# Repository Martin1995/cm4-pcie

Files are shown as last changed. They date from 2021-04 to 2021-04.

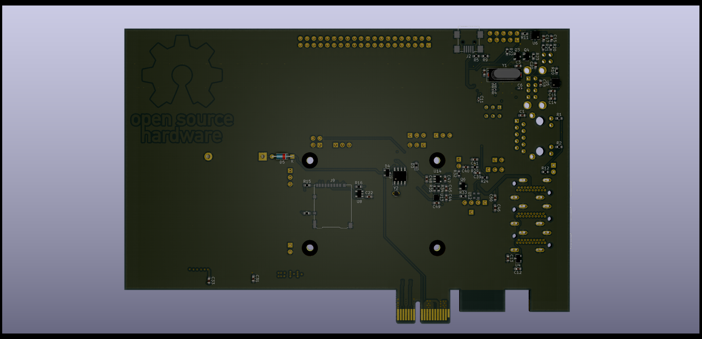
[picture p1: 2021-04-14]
CM4-pcie-rear.png

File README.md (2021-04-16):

# cm4-pcie
TODO:
-Connect HPD of HDMI In to the right pin on the Toshiba HDMI CSI-2 bridge

Feel free to copy the design, I'm not a Highspeed PCB expert, but if you want to use this PCB Design, to create a PCIe Card sized Raspberry Pi CM4 Carrier Board that can plug in to a PCIe Backplane feel free to do so.

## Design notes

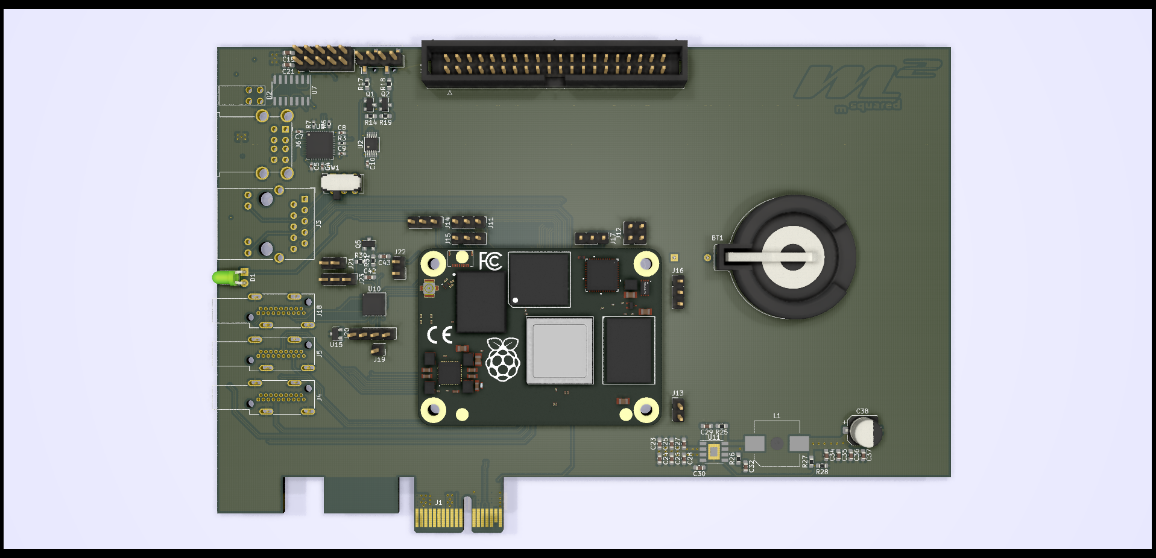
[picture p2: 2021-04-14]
CM4-pcie-front.png

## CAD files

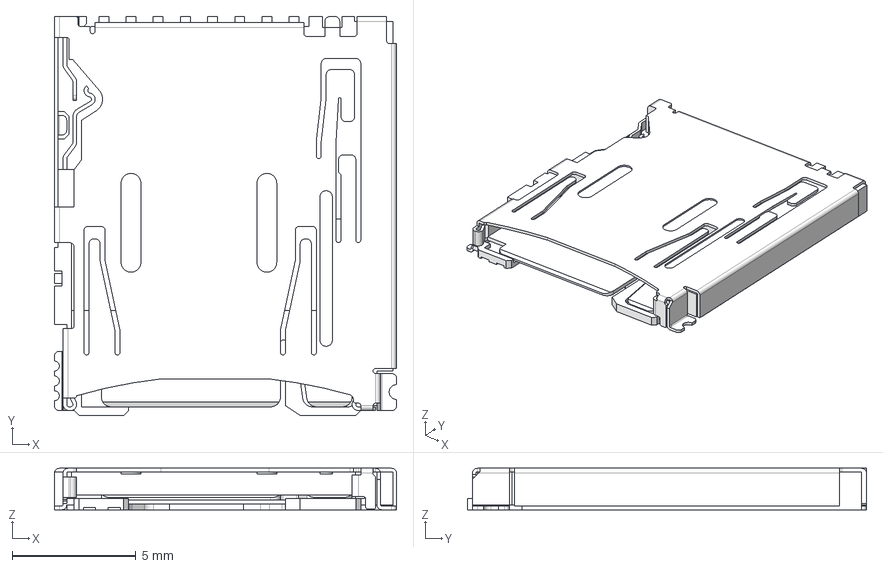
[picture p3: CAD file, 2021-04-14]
DM3AT-SF-PEJM5.stp
13.8 x 16.2 x 1.68 mm

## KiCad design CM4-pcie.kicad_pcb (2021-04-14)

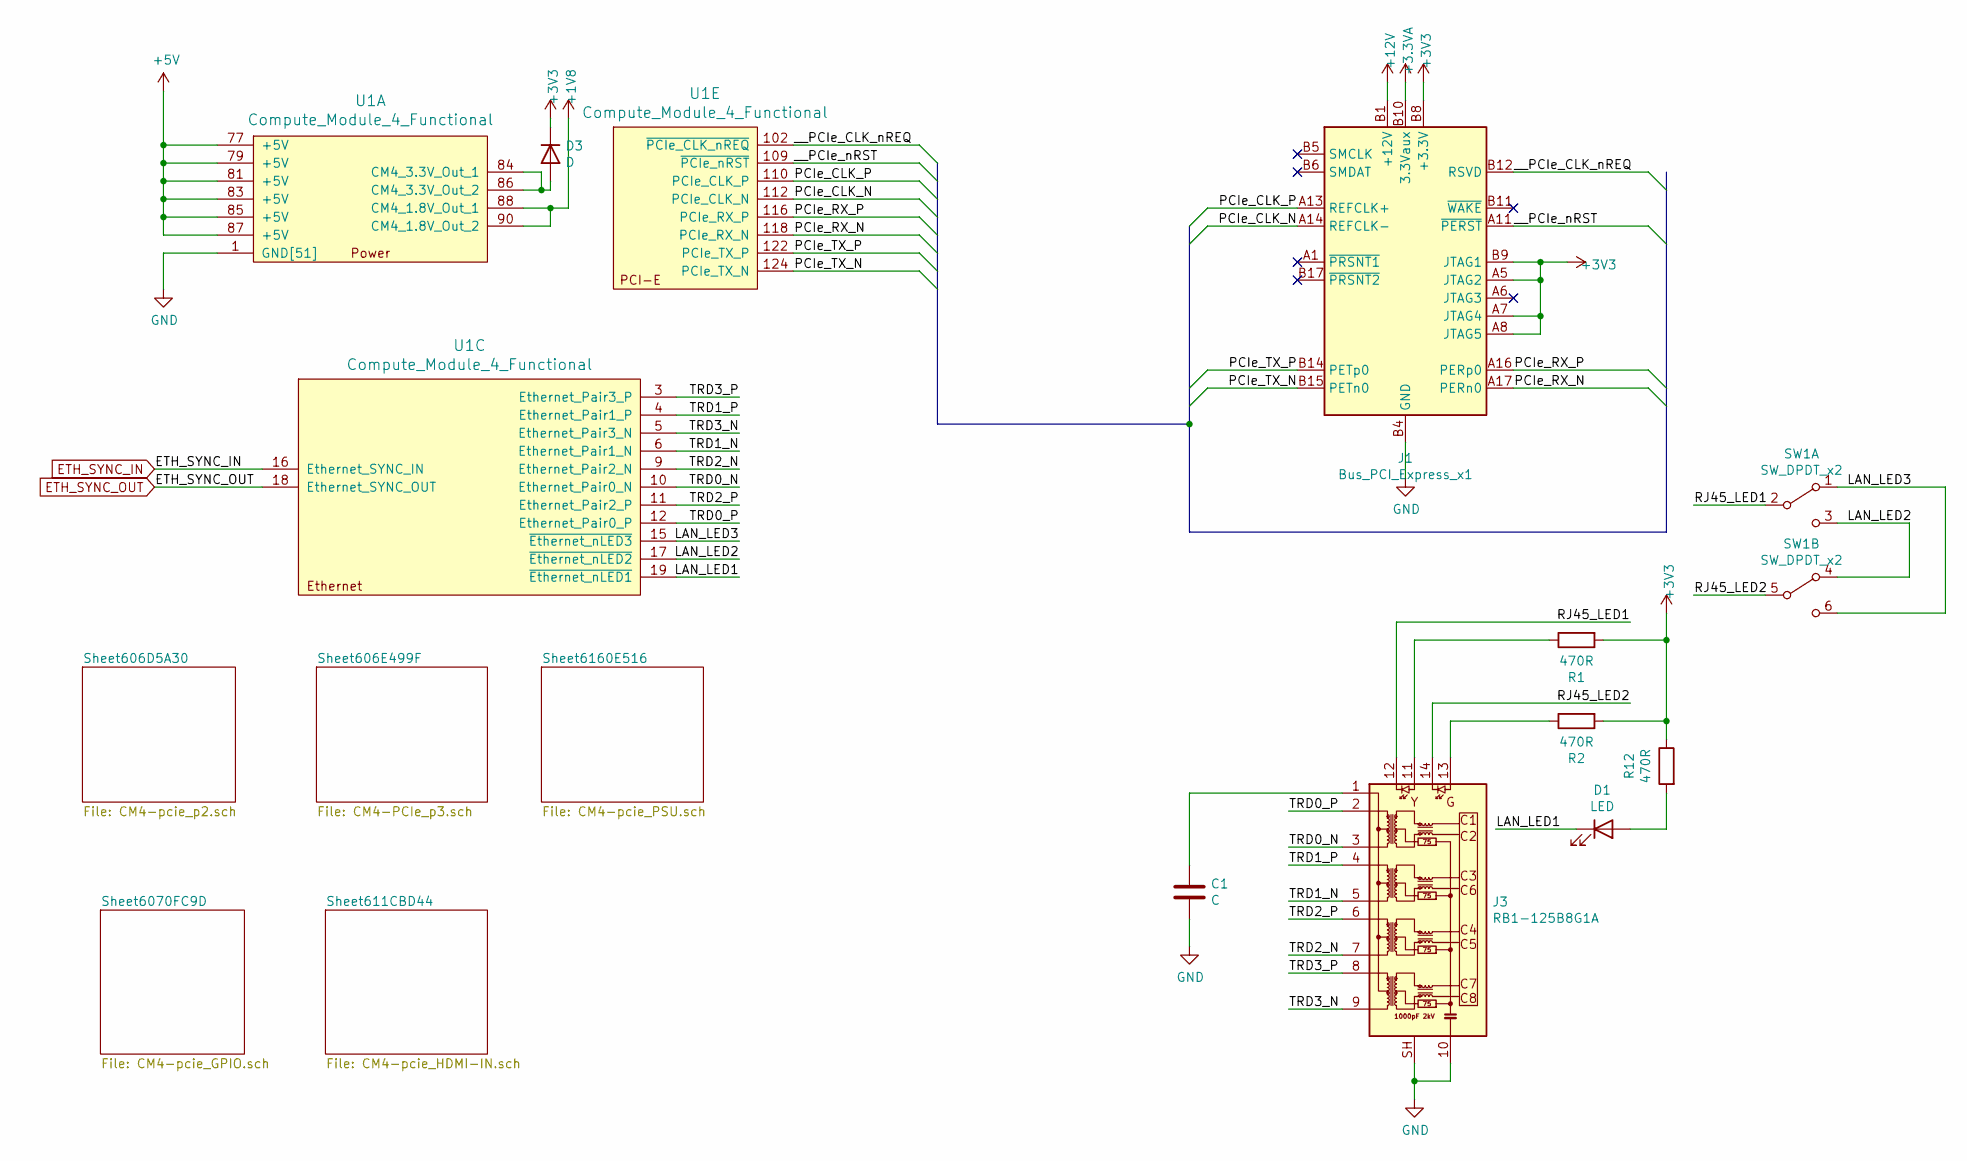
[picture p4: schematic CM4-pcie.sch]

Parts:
C1: C; C_0603_1608Metric_Pad1.08x0.95mm_HandSolder
D1: LED; LED_D3.0mm_Horizontal_O1.27mm_Z2.0mm
D3: D; D_0603_1608Metric_Pad1.05x0.95mm_HandSolder
J1: Bus_PCI_Express_x1; BUS_PCIexpress_x1
J3: RB1-125B8G1A; RJ45_Wuerth_7499111446_Horizontal
R1, R2, R12: 470R; R_0603_1608Metric_Pad0.98x0.95mm_HandSolder
SW1: SW_DPDT_x2; SW_CuK_JS202011AQN_DPDT_Angled
U1: Compute_Module_4_Functional; Raspberry-Pi-4-Compute-Module

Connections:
+1V8: U1.88 (CM4_1.8V_Out_1), U1.90 (CM4_1.8V_Out_2); also elsewhere on the board
+3.3VA: J1.B10 (3.3Vaux); also elsewhere on the board
+3V3: D3.1 (K), J1.A5 (JTAG2), J1.A7 (JTAG4), J1.A8 (JTAG5), J1.A9 (+3.3V), J1.A10 (+3.3V), J1.B8 (+3.3V), J1.B9 (JTAG1), R1.2, R2.2, R12.1; also elsewhere on the board
+5V: U1.77 (+5V), U1.79 (+5V), U1.81 (+5V), U1.83 (+5V), U1.85 (+5V), U1.87 (+5V); also elsewhere on the board
+12V: J1.A2 (+12V), J1.A3 (+12V), J1.B1 (+12V), J1.B2 (+12V), J1.B3 (+12V); also elsewhere on the board
/LAN_LED1: D1.1 (K), U1.19 (~Ethernet_nLED1)
/LAN_LED2: SW1.3 (C), SW1.4 (A), U1.17 (~Ethernet_nLED2)
/LAN_LED3: SW1.1 (A), SW1.6 (C), U1.15 (~Ethernet_nLED3)
/PCIe_CLK_N: J1.A14 (REFCLK-), U1.112 (PCIe_CLK_N)
/PCIe_CLK_P: J1.A13 (REFCLK+), U1.110 (PCIe_CLK_P)
/PCIe_RX_N: J1.A17 (PERn0), U1.118 (PCIe_RX_N)
/PCIe_RX_P: J1.A16 (PERp0), U1.116 (PCIe_RX_P)
/PCIe_TX_N: J1.B15 (PETn0), U1.124 (PCIe_TX_N)
/PCIe_TX_P: J1.B14 (PETp0), U1.122 (PCIe_TX_P)
/RJ45_LED1: J3.12, SW1.2 (B)
/RJ45_LED2: J3.14, SW1.5 (B)
/TRD0_N: J3.3 (TD1-), U1.10 (Ethernet_Pair0_N)
/TRD0_P: J3.2 (TD1+), U1.12 (Ethernet_Pair0_P)
/TRD1_N: J3.5 (TD2-), U1.6 (Ethernet_Pair1_N)
/TRD1_P: J3.4 (TD2+), U1.4 (Ethernet_Pair1_P)
/TRD2_N: J3.7 (TD3-), U1.9 (Ethernet_Pair2_N)
/TRD2_P: J3.6 (TD3+), U1.11 (Ethernet_Pair2_P)
/TRD3_N: J3.9 (TD4-), U1.5 (Ethernet_Pair3_N)
/TRD3_P: J3.8 (TD4+), U1.3 (Ethernet_Pair3_P)
/__PCIe_CLK_nREQ: J1.B12 (RSVD), U1.102 (~PCIe_CLK_nREQ)
/__PCIe_nRST: J1.A11 (~PERST), U1.109 (~PCIe_nRST)
ETH_SYNC_IN: U1.16 (Ethernet_SYNC_IN); also elsewhere on the board
ETH_SYNC_OUT: U1.18 (Ethernet_SYNC_OUT); also elsewhere on the board
GND: C1.2, J1.A4 (GND), J1.A12 (GND), J1.A15 (GND), J1.A18 (GND), J1.B4 (GND), J1.B7 (GND), J1.B13 (GND), J1.B16 (GND), J1.B18 (GND), J3.10 (GND), J3.SH, U1.1 (GND[51]), U1.2 (GND[51]), U1.7 (GND[51]), U1.8 (GND[51]), U1.13 (GND[51]), U1.14 (GND[51]), U1.22 (GND[51]), U1.23 (GND[51]), U1.32 (GND[51]), U1.33 (GND[51]), U1.42 (GND[51]), U1.43 (GND[51]), U1.52 (GND[51]), U1.53 (GND[51]), U1.59 (GND[51]), U1.60 (GND[51]), U1.65 (GND[51]), U1.66 (GND[51]), U1.71 (GND[51]), U1.74 (GND[51]), U1.98 (GND[51]), U1.107 (GND[51]), U1.108 (GND[51]), U1.113 (GND[51]), U1.114 (GND[51]), U1.119 (GND[51]), U1.120 (GND[51]), U1.125 (GND[51]), U1.126 (GND[51]), U1.131 (GND[51]), U1.132 (GND[51]), U1.137 (GND[51]), U1.138 (GND[51]), U1.144 (GND[51]), U1.150 (GND[51]), U1.155 (GND[51]), U1.156 (GND[51]), U1.161 (GND[51]), U1.162 (GND[51]), U1.167 (GND[51]), U1.168 (GND[51]), U1.173 (GND[51]), U1.174 (GND[51]), U1.179 (GND[51]), U1.180 (GND[51]), U1.185 (GND[51]), U1.186 (GND[51]), U1.191 (GND[51]), U1.192 (GND[51]), U1.197 (GND[51]), U1.198 (GND[51]); also elsewhere on the board
unnamed: C1.1, J3.1 (CT)
unnamed: D1.2 (A), R12.2
unnamed: D3.2 (A), U1.84 (CM4_3.3V_Out_1), U1.86 (CM4_3.3V_Out_2)
unnamed: J3.11, R1.1
unnamed: J3.13, R2.1

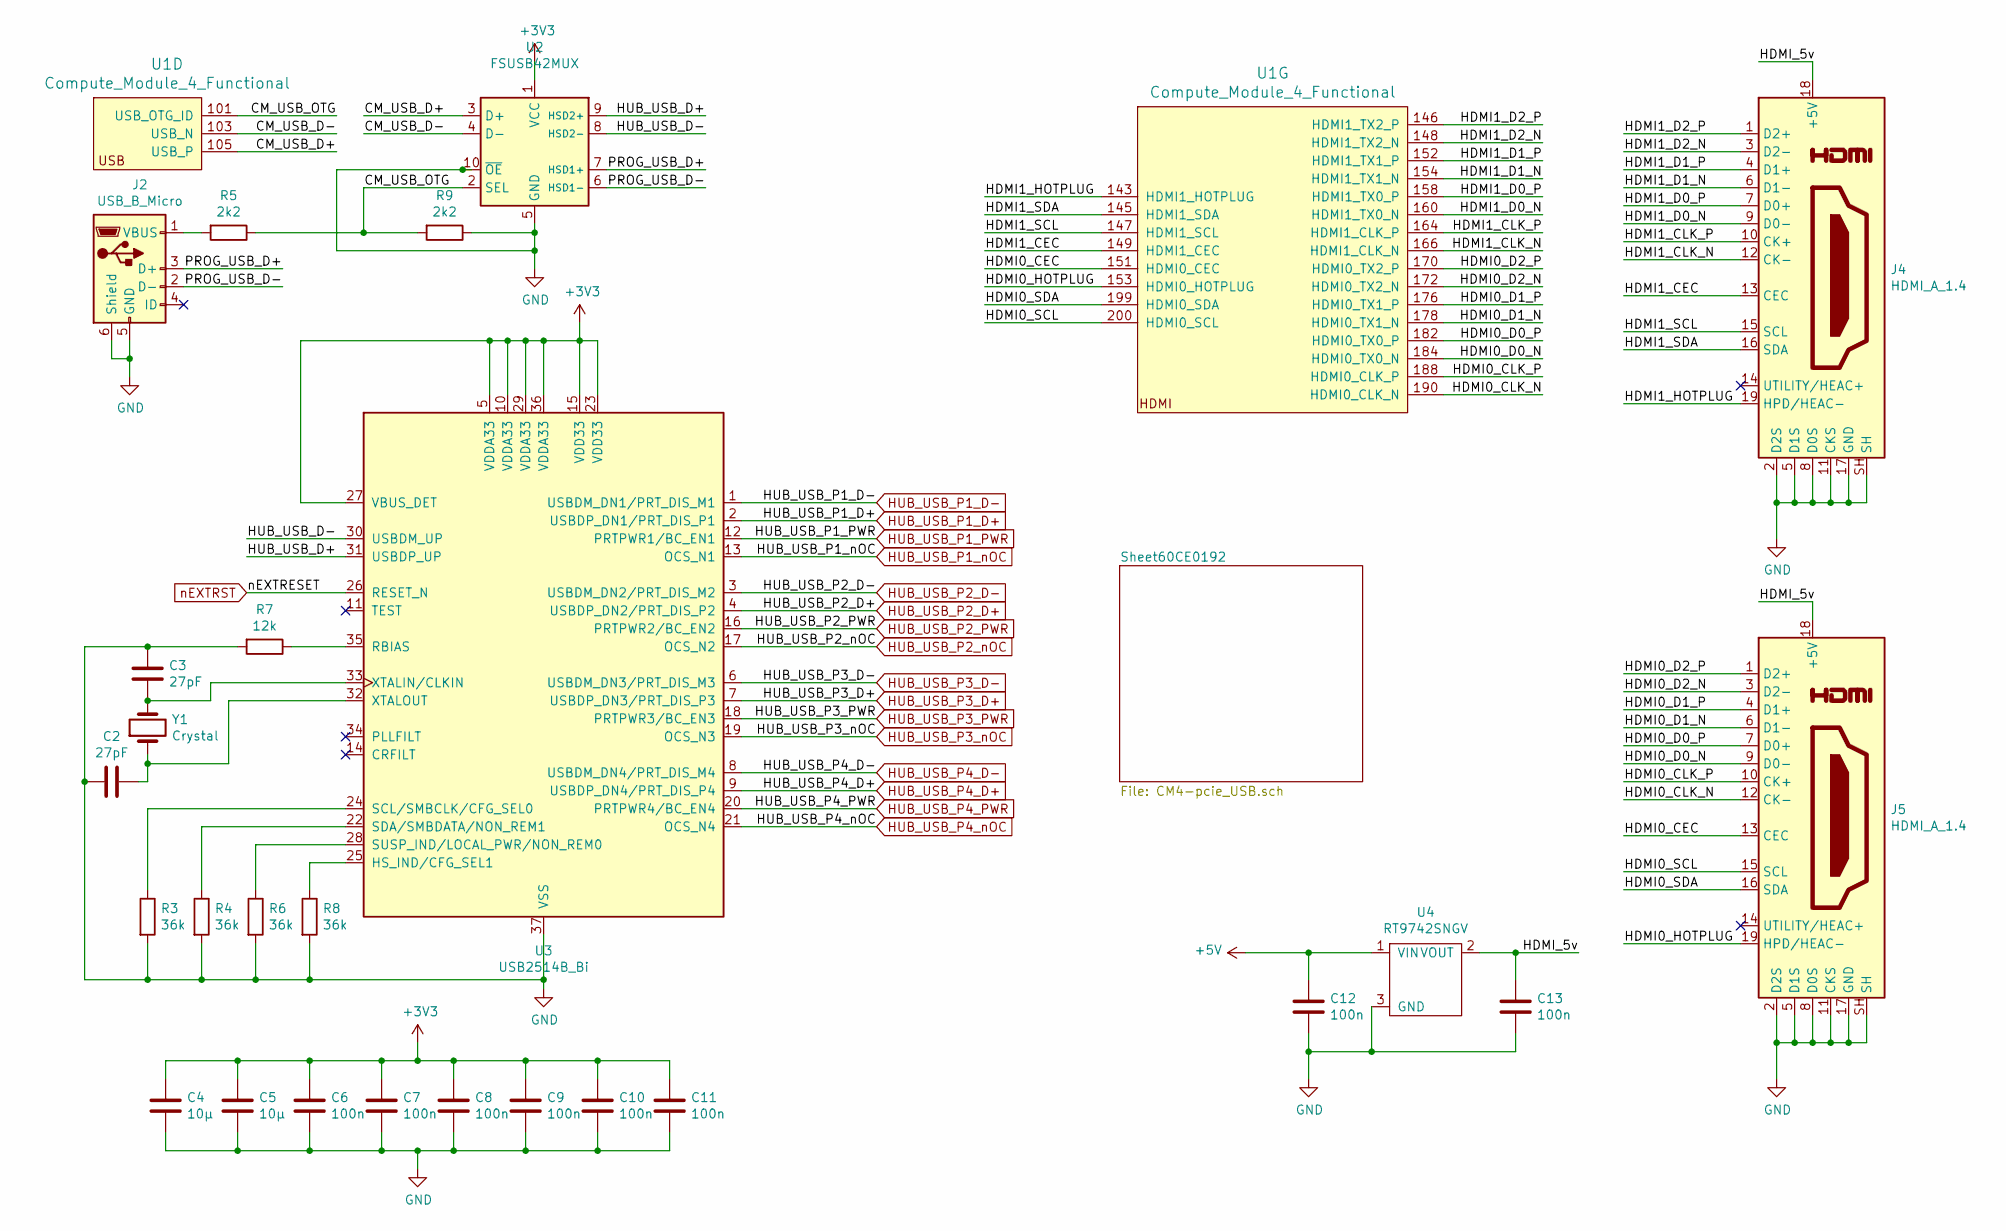
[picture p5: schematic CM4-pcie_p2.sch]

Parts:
C2, C3: 27pF; C_0603_1608Metric_Pad1.08x0.95mm_HandSolder
C4, C5: 10µ; C_0402_1005Metric_Pad0.74x0.62mm_HandSolder
C6, C7, C8, C9, C10, C11: 100n; C_0402_1005Metric_Pad0.74x0.62mm_HandSolder
C12, C13: 100n; C_0603_1608Metric_Pad1.08x0.95mm_HandSolder
J2: USB_B_Micro; USB_Mini-B_Wuerth_65100516121_Horizontal
J4, J5: HDMI_A_1.4; HDMI_A_Kycon_KDMIX-SL1-NS-WS-B15_VerticalRightAngle
R3, R4, R6, R8: 36k; R_0402_1005Metric_Pad0.72x0.64mm_HandSolder
R5, R9: 2k2; R_0603_1608Metric_Pad0.98x0.95mm_HandSolder
R7: 12k; R_0402_1005Metric_Pad0.72x0.64mm_HandSolder
U1: Compute_Module_4_Functional; Raspberry-Pi-4-Compute-Module
U2: FSUSB42MUX; MSOP-10_3x3mm_P0.5mm
U3: USB2514B_Bi; QFN-36-1EP_6x6mm_P0.5mm_EP3.7x3.7mm
U4: RT9742SNGV; SOT-23
Y1: Crystal; Crystal_SMD_HC49-SD

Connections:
+3V3: C4.1, C5.1, C6.1, C7.1, C8.1, C9.1, C10.1, C11.1, U2.1 (VCC), U3.5 (VDDA33), U3.10 (VDDA33), U3.15 (VDD33), U3.23 (VDD33), U3.27 (VBUS_DET), U3.29 (VDDA33), U3.36 (VDDA33); also elsewhere on the board
+5V: C12.1, U4.1 (VIN); also elsewhere on the board
/Sheet606D5A30/CM_USB_D+: U1.105 (USB_P), U2.3 (D+)
/Sheet606D5A30/CM_USB_D-: U1.103 (USB_N), U2.4 (D-)
/Sheet606D5A30/CM_USB_OTG: R5.1, R9.2, U1.101 (USB_OTG_ID), U2.2 (SEL)
/Sheet606D5A30/HDMI0_CEC: J5.13 (CEC), U1.151 (HDMI0_CEC)
/Sheet606D5A30/HDMI0_CLK_N: J5.12 (CK-), U1.190 (HDMI0_CLK_N)
/Sheet606D5A30/HDMI0_CLK_P: J5.10 (CK+), U1.188 (HDMI0_CLK_P)
/Sheet606D5A30/HDMI0_D0_N: J5.9 (D0-), U1.184 (HDMI0_TX0_N)
/Sheet606D5A30/HDMI0_D0_P: J5.7 (D0+), U1.182 (HDMI0_TX0_P)
/Sheet606D5A30/HDMI0_D1_N: J5.6 (D1-), U1.178 (HDMI0_TX1_N)
/Sheet606D5A30/HDMI0_D1_P: J5.4 (D1+), U1.176 (HDMI0_TX1_P)
/Sheet606D5A30/HDMI0_D2_N: J5.3 (D2-), U1.172 (HDMI0_TX2_N)
/Sheet606D5A30/HDMI0_D2_P: J5.1 (D2+), U1.170 (HDMI0_TX2_P)
/Sheet606D5A30/HDMI0_HOTPLUG: J5.19 (HPD/HEAC-), U1.153 (HDMI0_HOTPLUG)
/Sheet606D5A30/HDMI0_SCL: J5.15 (SCL), U1.200 (HDMI0_SCL)
/Sheet606D5A30/HDMI0_SDA: J5.16 (SDA), U1.199 (HDMI0_SDA)
/Sheet606D5A30/HDMI1_CEC: J4.13 (CEC), U1.149 (HDMI1_CEC)
/Sheet606D5A30/HDMI1_CLK_N: J4.12 (CK-), U1.166 (HDMI1_CLK_N)
/Sheet606D5A30/HDMI1_CLK_P: J4.10 (CK+), U1.164 (HDMI1_CLK_P)
/Sheet606D5A30/HDMI1_D0_N: J4.9 (D0-), U1.160 (HDMI1_TX0_N)
/Sheet606D5A30/HDMI1_D0_P: J4.7 (D0+), U1.158 (HDMI1_TX0_P)
/Sheet606D5A30/HDMI1_D1_N: J4.6 (D1-), U1.154 (HDMI1_TX1_N)
/Sheet606D5A30/HDMI1_D1_P: J4.4 (D1+), U1.152 (HDMI1_TX1_P)
/Sheet606D5A30/HDMI1_D2_N: J4.3 (D2-), U1.148 (HDMI1_TX2_N)
/Sheet606D5A30/HDMI1_D2_P: J4.1 (D2+), U1.146 (HDMI1_TX2_P)
/Sheet606D5A30/HDMI1_HOTPLUG: J4.19 (HPD/HEAC-), U1.143 (HDMI1_HOTPLUG)
/Sheet606D5A30/HDMI1_SCL: J4.15 (SCL), U1.147 (HDMI1_SCL)
/Sheet606D5A30/HDMI1_SDA: J4.16 (SDA), U1.145 (HDMI1_SDA)
/Sheet606D5A30/HDMI_5v: C13.1, J4.18 (+5V), J5.18 (+5V), U4.2 (VOUT)
/Sheet606D5A30/HUB_USB_D+: U2.9 (HSD2+), U3.31 (USBDP_UP)
/Sheet606D5A30/HUB_USB_D-: U2.8 (HSD2-), U3.30 (USBDM_UP)
/Sheet606D5A30/PROG_USB_D+: J2.3 (D+), U2.7 (HSD1+)
/Sheet606D5A30/PROG_USB_D-: J2.2 (D-), U2.6 (HSD1-)
GND: C2.1, C3.2, C4.2, C5.2, C6.2, C7.2, C8.2, C9.2, C10.2, C11.2, C12.2, C13.2, J2.5 (GND), J2.6 (Shield), J4.2 (D2S), J4.5 (D1S), J4.8 (D0S), J4.11 (CKS), J4.17 (GND), J4.SH, J5.2 (D2S), J5.5 (D1S), J5.8 (D0S), J5.11 (CKS), J5.17 (GND), J5.SH, R3.2, R4.2, R6.2, R7.2, R8.2, R9.1, U2.5 (GND), U2.10 (~OE), U3.37 (VSS), U4.3 (GND); also elsewhere on the board
HUB_USB_P1_D+: U3.2 (USBDP_DN1/PRT_DIS_P1); also elsewhere on the board
HUB_USB_P1_D-: U3.1 (USBDM_DN1/PRT_DIS_M1); also elsewhere on the board
HUB_USB_P1_PWR: U3.12 (PRTPWR1/BC_EN1); also elsewhere on the board
HUB_USB_P1_nOC: U3.13 (OCS_N1); also elsewhere on the board
HUB_USB_P2_D+: U3.4 (USBDP_DN2/PRT_DIS_P2); also elsewhere on the board
HUB_USB_P2_D-: U3.3 (USBDM_DN2/PRT_DIS_M2); also elsewhere on the board
HUB_USB_P2_PWR: U3.16 (PRTPWR2/BC_EN2); also elsewhere on the board
HUB_USB_P2_nOC: U3.17 (OCS_N2); also elsewhere on the board
HUB_USB_P3_D+: U3.7 (USBDP_DN3/PRT_DIS_P3); also elsewhere on the board
HUB_USB_P3_D-: U3.6 (USBDM_DN3/PRT_DIS_M3); also elsewhere on the board
HUB_USB_P3_PWR: U3.18 (PRTPWR3/BC_EN3); also elsewhere on the board
HUB_USB_P3_nOC: U3.19 (OCS_N3); also elsewhere on the board
HUB_USB_P4_D+: U3.9 (USBDP_DN4/PRT_DIS_P4); also elsewhere on the board
HUB_USB_P4_D-: U3.8 (USBDM_DN4/PRT_DIS_M4); also elsewhere on the board
HUB_USB_P4_PWR: U3.20 (PRTPWR4/BC_EN4); also elsewhere on the board
HUB_USB_P4_nOC: U3.21 (OCS_N4); also elsewhere on the board
unnamed: C2.2, U3.32 (XTALOUT), Y1.1
unnamed: C3.1, U3.33 (XTALIN/CLKIN), Y1.2
unnamed: J2.1 (VBUS), R5.2
unnamed: R3.1, U3.24 (SCL/SMBCLK/CFG_SEL0)
unnamed: R4.1, U3.22 (SDA/SMBDATA/NON_REM1)
unnamed: R6.1, U3.28 (SUSP_IND/LOCAL_PWR/NON_REM0)
unnamed: R7.1, U3.35 (RBIAS)
unnamed: R8.1, U3.25 (HS_IND/CFG_SEL1)
nEXTRST: U3.26 (RESET_N); also elsewhere on the board

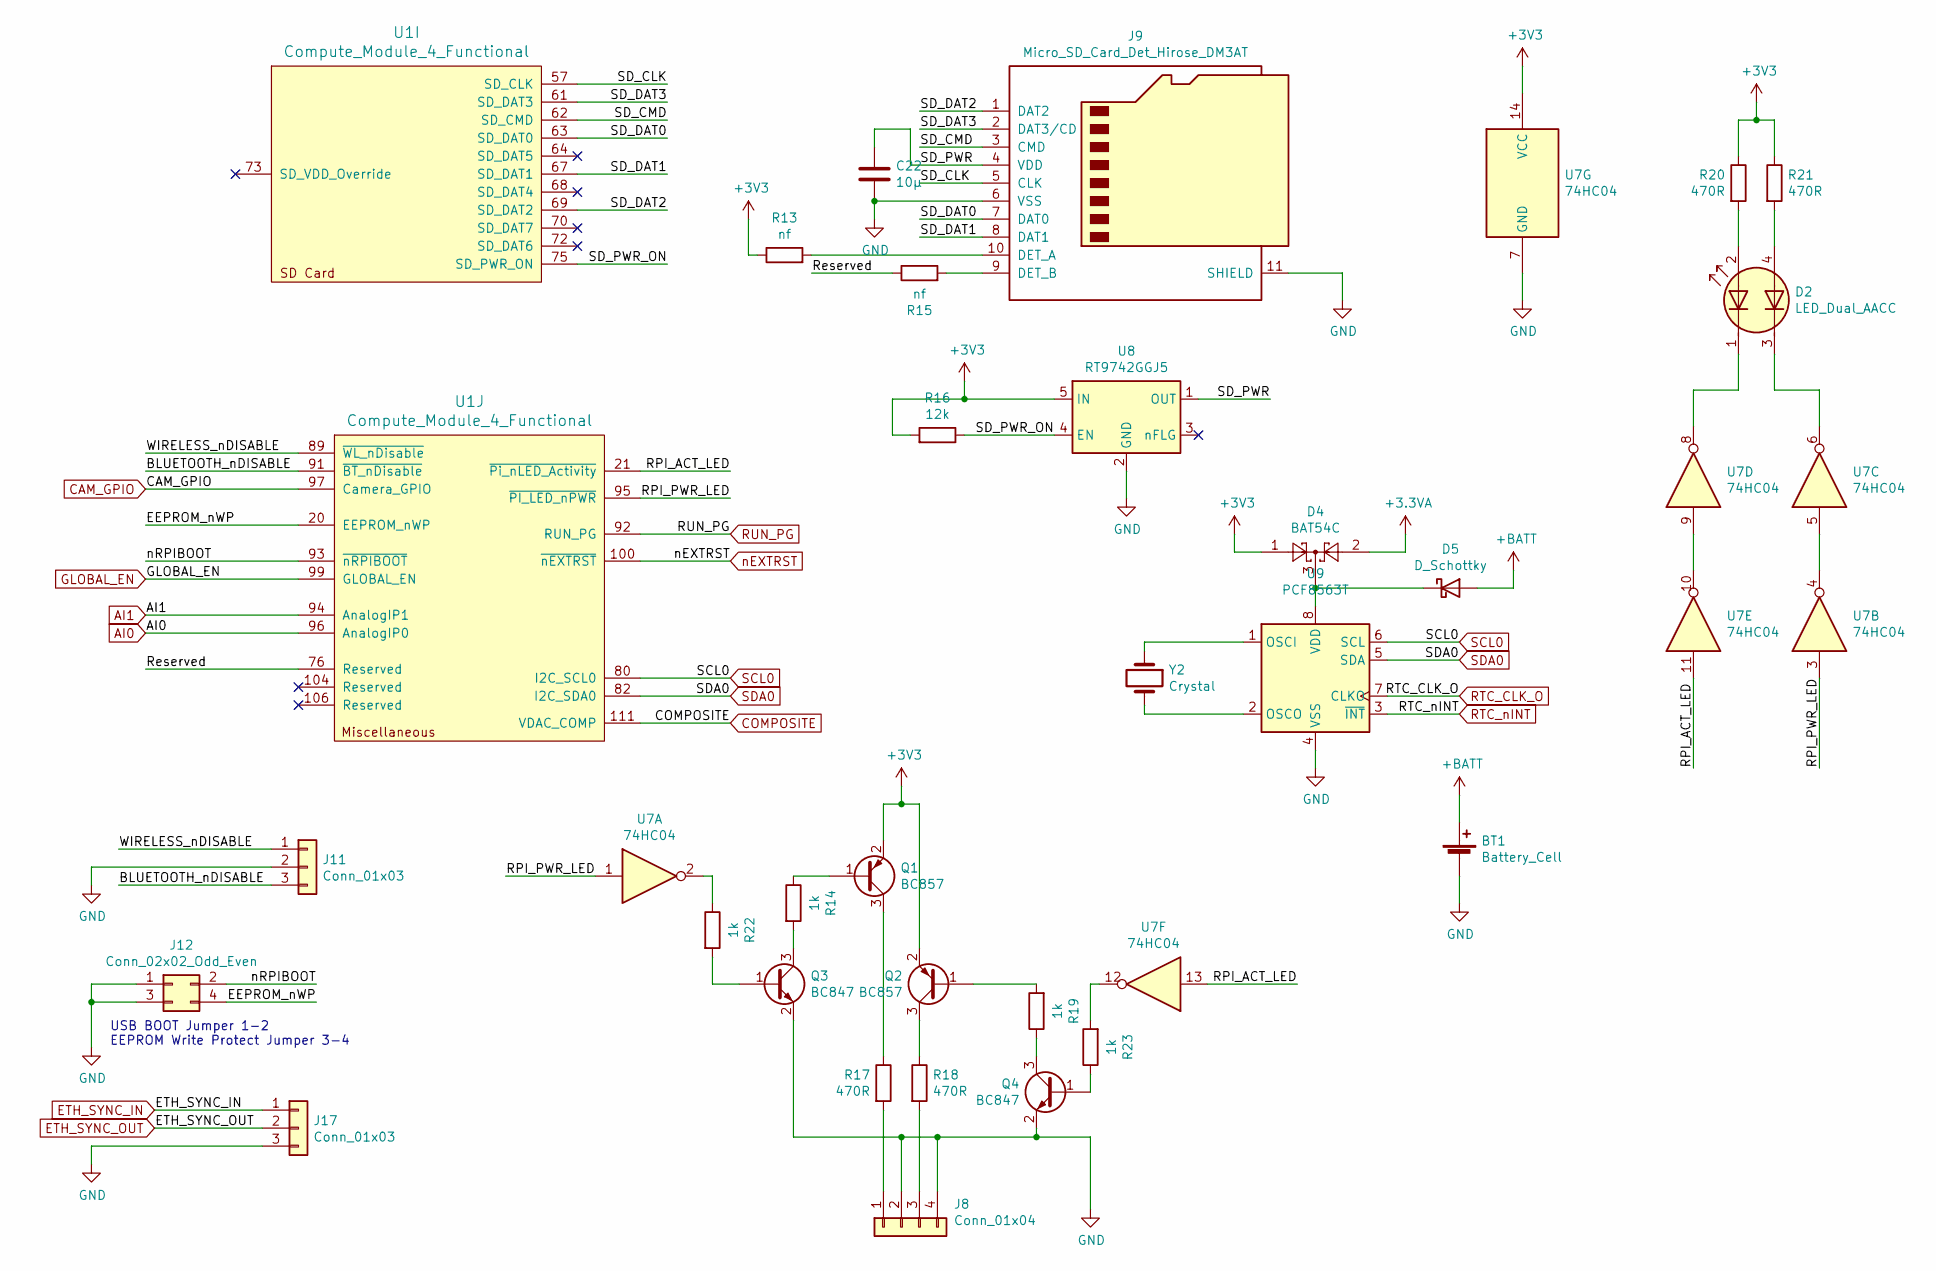
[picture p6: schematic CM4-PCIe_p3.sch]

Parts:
BT1: Battery_Cell; BatteryHolder_Keystone_106_1x20mm
C22: 10µ; C_0603_1608Metric_Pad1.08x0.95mm_HandSolder
D2: LED_Dual_AACC; DIAL_553-0112-20
D4: BAT54C; SOT-23
D5: D_Schottky
J8: Conn_01x04; PinHeader_1x04_P2.54mm_Vertical_SMD_Pin1Left
J9: Micro_SD_Card_Det_Hirose_DM3AT; microSD_HC_Hirose_DM3AT-SF-PEJM5
J11, J17: Conn_01x03; PinHeader_1x03_P2.54mm_Vertical
J12: Conn_02x02_Odd_Even; PinHeader_2x02_P2.54mm_Vertical
Q1, Q2: BC857; SOT-23
Q3, Q4: BC847; SOT-23
R13, R15: nf; R_0603_1608Metric_Pad0.98x0.95mm_HandSolder
R14, R19, R22, R23: 1k; R_0603_1608Metric_Pad0.98x0.95mm_HandSolder
R16: 12k; R_0603_1608Metric_Pad0.98x0.95mm_HandSolder
R17, R18, R20, R21: 470R; R_0603_1608Metric_Pad0.98x0.95mm_HandSolder
U1: Compute_Module_4_Functional; Raspberry-Pi-4-Compute-Module
U7: 74HC04; SO-14_3.9x8.65mm_P1.27mm
U8: RT9742GGJ5; SOT-23-5
U9: PCF8563T; SOIC-8_3.9x4.9mm_P1.27mm
Y2: Crystal; Crystal_Round_D1.5mm_Vertical

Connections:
+3.3VA: D4.2; also elsewhere on the board
+3V3: D4.1, Q1.2 (E), Q2.2 (E), R13.1, R16.2, R20.1, R21.1, U7.14 (VCC), U8.5 (IN); also elsewhere on the board
+BATT: BT1.1 (+), D5.2 (A)
/Sheet606E499F/BLUETOOTH_nDISABLE: J11.3, U1.91 (~BT_nDisable)
/Sheet606E499F/EEPROM_nWP: J12.4, U1.20 (EEPROM_nWP)
/Sheet606E499F/RPI_ACT_LED: U1.21 (~Pi_nLED_Activity), U7.11, U7.13
/Sheet606E499F/RPI_PWR_LED: U1.95 (~PI_LED_nPWR), U7.1, U7.3
/Sheet606E499F/Reserved: R15.1, U1.76 (Reserved)
/Sheet606E499F/SD_CLK: J9.5 (CLK), U1.57 (SD_CLK)
/Sheet606E499F/SD_CMD: J9.3 (CMD), U1.62 (SD_CMD)
/Sheet606E499F/SD_DAT0: J9.7 (DAT0), U1.63 (SD_DAT0)
/Sheet606E499F/SD_DAT1: J9.8 (DAT1), U1.67 (SD_DAT1)
/Sheet606E499F/SD_DAT2: J9.1 (DAT2), U1.69 (SD_DAT2)
/Sheet606E499F/SD_DAT3: J9.2 (DAT3/CD), U1.61 (SD_DAT3)
/Sheet606E499F/SD_PWR: C22.1, J9.4 (VDD), U8.1 (OUT)
/Sheet606E499F/SD_PWR_ON: R16.1, U1.75 (SD_PWR_ON), U8.4 (EN)
/Sheet606E499F/WIRELESS_nDISABLE: J11.1, U1.89 (~WL_nDisable)
/Sheet606E499F/nRPIBOOT: J12.2, U1.93 (~nRPIBOOT)
AI0: U1.96 (AnalogIP0); also elsewhere on the board
AI1: U1.94 (AnalogIP1); also elsewhere on the board
CAM_GPIO: U1.97 (Camera_GPIO); also elsewhere on the board
COMPOSITE: U1.111 (VDAC_COMP); also elsewhere on the board
ETH_SYNC_IN: J17.1; also elsewhere on the board
ETH_SYNC_OUT: J17.2; also elsewhere on the board
GLOBAL_EN: U1.99 (GLOBAL_EN); also elsewhere on the board
GND: BT1.2 (-), C22.2, J8.2, J8.4, J9.6 (VSS), J9.11 (SHIELD), J11.2, J12.1, J12.3, J17.3, Q3.2 (E), Q4.2 (E), U7.7 (GND), U8.2 (GND), U9.4 (VSS); also elsewhere on the board
unnamed: D2.1 (A1), U7.8
unnamed: D2.2 (K1), R20.2
unnamed: D2.3 (A2), U7.6
unnamed: D2.4 (K2), R21.2
unnamed: D4.3, D5.1 (K), U9.8 (VDD)
unnamed: J8.1, R17.2
unnamed: J8.3, R18.2
unnamed: J9.9 (DET_B), R15.2
unnamed: J9.10 (DET_A), R13.2
unnamed: Q1.1 (B), R14.1
unnamed: Q1.3 (C), R17.1
unnamed: Q2.1 (B), R19.2
unnamed: Q2.3 (C), R18.1
unnamed: Q3.1 (B), R22.2
unnamed: Q3.3 (C), R14.2
unnamed: Q4.1 (B), R23.1
unnamed: Q4.3 (C), R19.1
unnamed: R22.1, U7.2
unnamed: R23.2, U7.12
unnamed: U7.4, U7.5
unnamed: U7.9, U7.10
unnamed: U9.1 (OSCI), Y2.1
unnamed: U9.2 (OSCO), Y2.2
RTC_CLK_O: U9.7 (CLKO); also elsewhere on the board
RTC_nINT: U9.3 (~INT~); also elsewhere on the board
RUN_PG: U1.92 (RUN_PG); also elsewhere on the board
SCL0: U1.80 (I2C_SCL0), U9.6 (SCL); also elsewhere on the board
SDA0: U1.82 (I2C_SDA0), U9.5 (SDA); also elsewhere on the board
nEXTRST: U1.100 (~nEXTRST); also elsewhere on the board

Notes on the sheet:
USB BOOT Jumper 1-2 EEPROM Write Protect Jumper 3-4

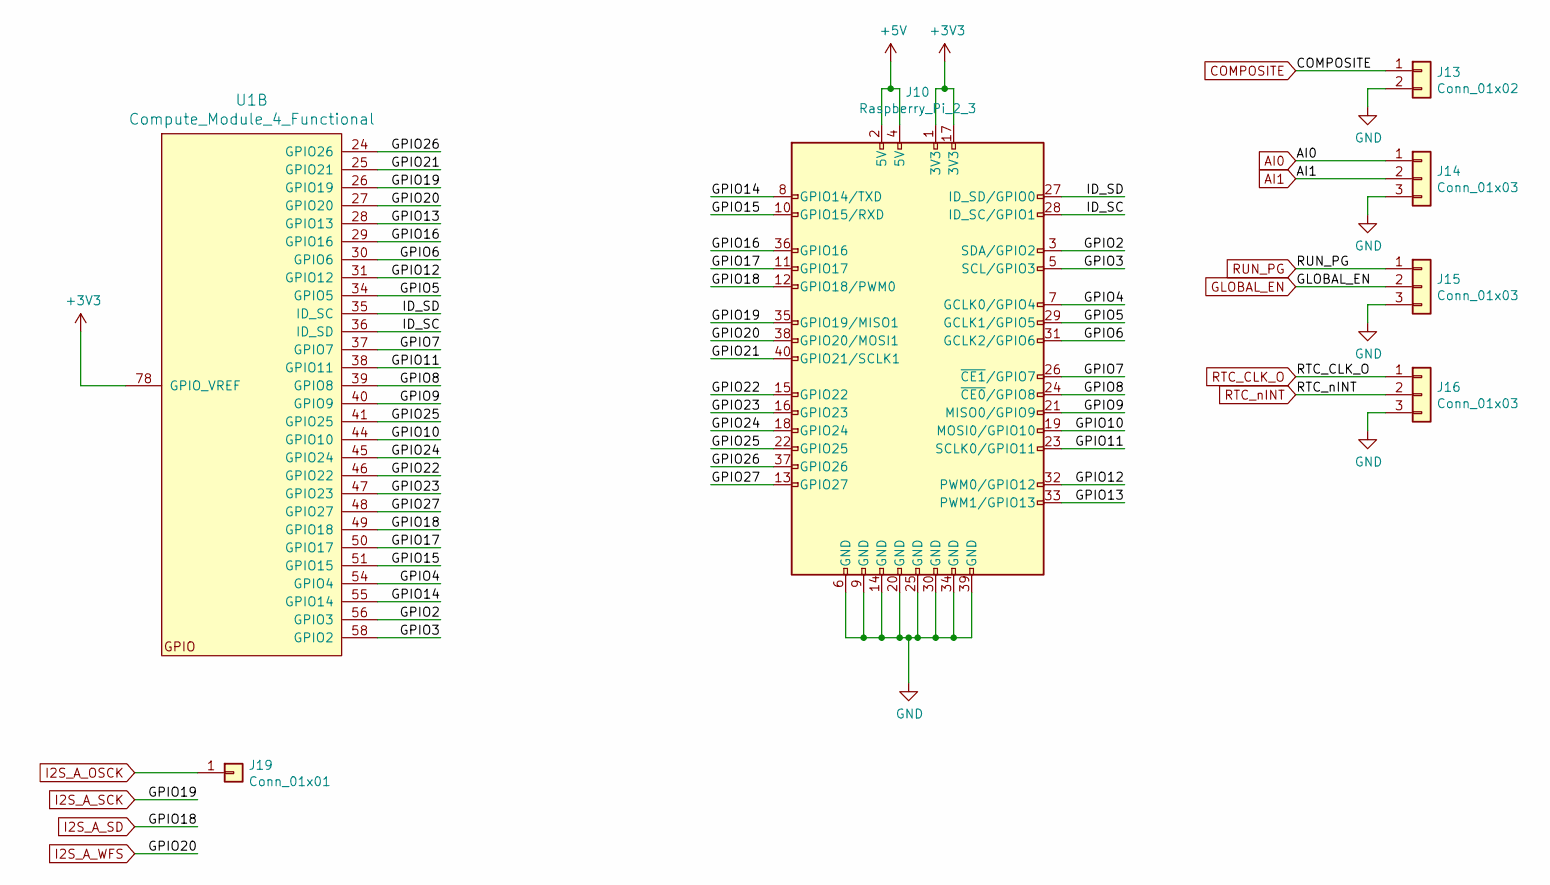
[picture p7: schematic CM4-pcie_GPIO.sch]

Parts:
J10: Raspberry_Pi_2_3; IDC-Header_2x20_P2.54mm_Vertical
J13: Conn_01x02; PinHeader_1x02_P2.54mm_Vertical
J14, J15, J16: Conn_01x03; PinHeader_1x03_P2.54mm_Vertical
J19: Conn_01x01; PinHeader_1x01_P2.54mm_Vertical
U1: Compute_Module_4_Functional; Raspberry-Pi-4-Compute-Module

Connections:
+3V3: J10.1 (3V3), J10.17 (3V3), U1.78 (GPIO_VREF); also elsewhere on the board
+5V: J10.2 (5V), J10.4 (5V); also elsewhere on the board
/Sheet6070FC9D/GPIO2: J10.3 (SDA/GPIO2), U1.56 (GPIO3)
/Sheet6070FC9D/GPIO3: J10.5 (SCL/GPIO3), U1.58 (GPIO2)
/Sheet6070FC9D/GPIO4: J10.7 (GCLK0/GPIO4), U1.54 (GPIO4)
/Sheet6070FC9D/GPIO5: J10.29 (GCLK1/GPIO5), U1.34 (GPIO5)
/Sheet6070FC9D/GPIO6: J10.31 (GCLK2/GPIO6), U1.30 (GPIO6)
/Sheet6070FC9D/GPIO7: J10.26 (~CE1~/GPIO7), U1.37 (GPIO7)
/Sheet6070FC9D/GPIO8: J10.24 (~CE0~/GPIO8), U1.39 (GPIO8)
/Sheet6070FC9D/GPIO9: J10.21 (MISO0/GPIO9), U1.40 (GPIO9)
/Sheet6070FC9D/GPIO10: J10.19 (MOSI0/GPIO10), U1.44 (GPIO10)
/Sheet6070FC9D/GPIO11: J10.23 (SCLK0/GPIO11), U1.38 (GPIO11)
/Sheet6070FC9D/GPIO12: J10.32 (PWM0/GPIO12), U1.31 (GPIO12)
/Sheet6070FC9D/GPIO13: J10.33 (PWM1/GPIO13), U1.28 (GPIO13)
/Sheet6070FC9D/GPIO14: J10.8 (GPIO14/TXD), U1.55 (GPIO14)
/Sheet6070FC9D/GPIO15: J10.10 (GPIO15/RXD), U1.51 (GPIO15)
/Sheet6070FC9D/GPIO16: J10.36 (GPIO16), U1.29 (GPIO16)
/Sheet6070FC9D/GPIO17: J10.11 (GPIO17), U1.50 (GPIO17)
/Sheet6070FC9D/GPIO21: J10.40 (GPIO21/SCLK1), U1.25 (GPIO21)
/Sheet6070FC9D/GPIO22: J10.15 (GPIO22), U1.46 (GPIO22)
/Sheet6070FC9D/GPIO23: J10.16 (GPIO23), U1.47 (GPIO23)
/Sheet6070FC9D/GPIO24: J10.18 (GPIO24), U1.45 (GPIO24)
/Sheet6070FC9D/GPIO25: J10.22 (GPIO25), U1.41 (GPIO25)
/Sheet6070FC9D/GPIO26: J10.37 (GPIO26), U1.24 (GPIO26)
/Sheet6070FC9D/GPIO27: J10.13 (GPIO27), U1.48 (GPIO27)
/Sheet6070FC9D/ID_SC: J10.28 (ID_SC/GPIO1), U1.36 (ID_SD)
/Sheet6070FC9D/ID_SD: J10.27 (ID_SD/GPIO0), U1.35 (ID_SC)
AI0: J14.1; also elsewhere on the board
AI1: J14.2; also elsewhere on the board
COMPOSITE: J13.1; also elsewhere on the board
GLOBAL_EN: J15.2; also elsewhere on the board
GND: J10.6 (GND), J10.9 (GND), J10.14 (GND), J10.20 (GND), J10.25 (GND), J10.30 (GND), J10.34 (GND), J10.39 (GND), J13.2, J14.3, J15.3, J16.3; also elsewhere on the board
I2S_A_OSCK: J19.1; also elsewhere on the board
I2S_A_SCK: J10.35 (GPIO19/MISO1), U1.26 (GPIO19); also elsewhere on the board
I2S_A_SD: J10.12 (GPIO18/PWM0), U1.49 (GPIO18); also elsewhere on the board
I2S_A_WFS: J10.38 (GPIO20/MOSI1), U1.27 (GPIO20); also elsewhere on the board
RTC_CLK_O: J16.1; also elsewhere on the board
RTC_nINT: J16.2; also elsewhere on the board
RUN_PG: J15.1; also elsewhere on the board

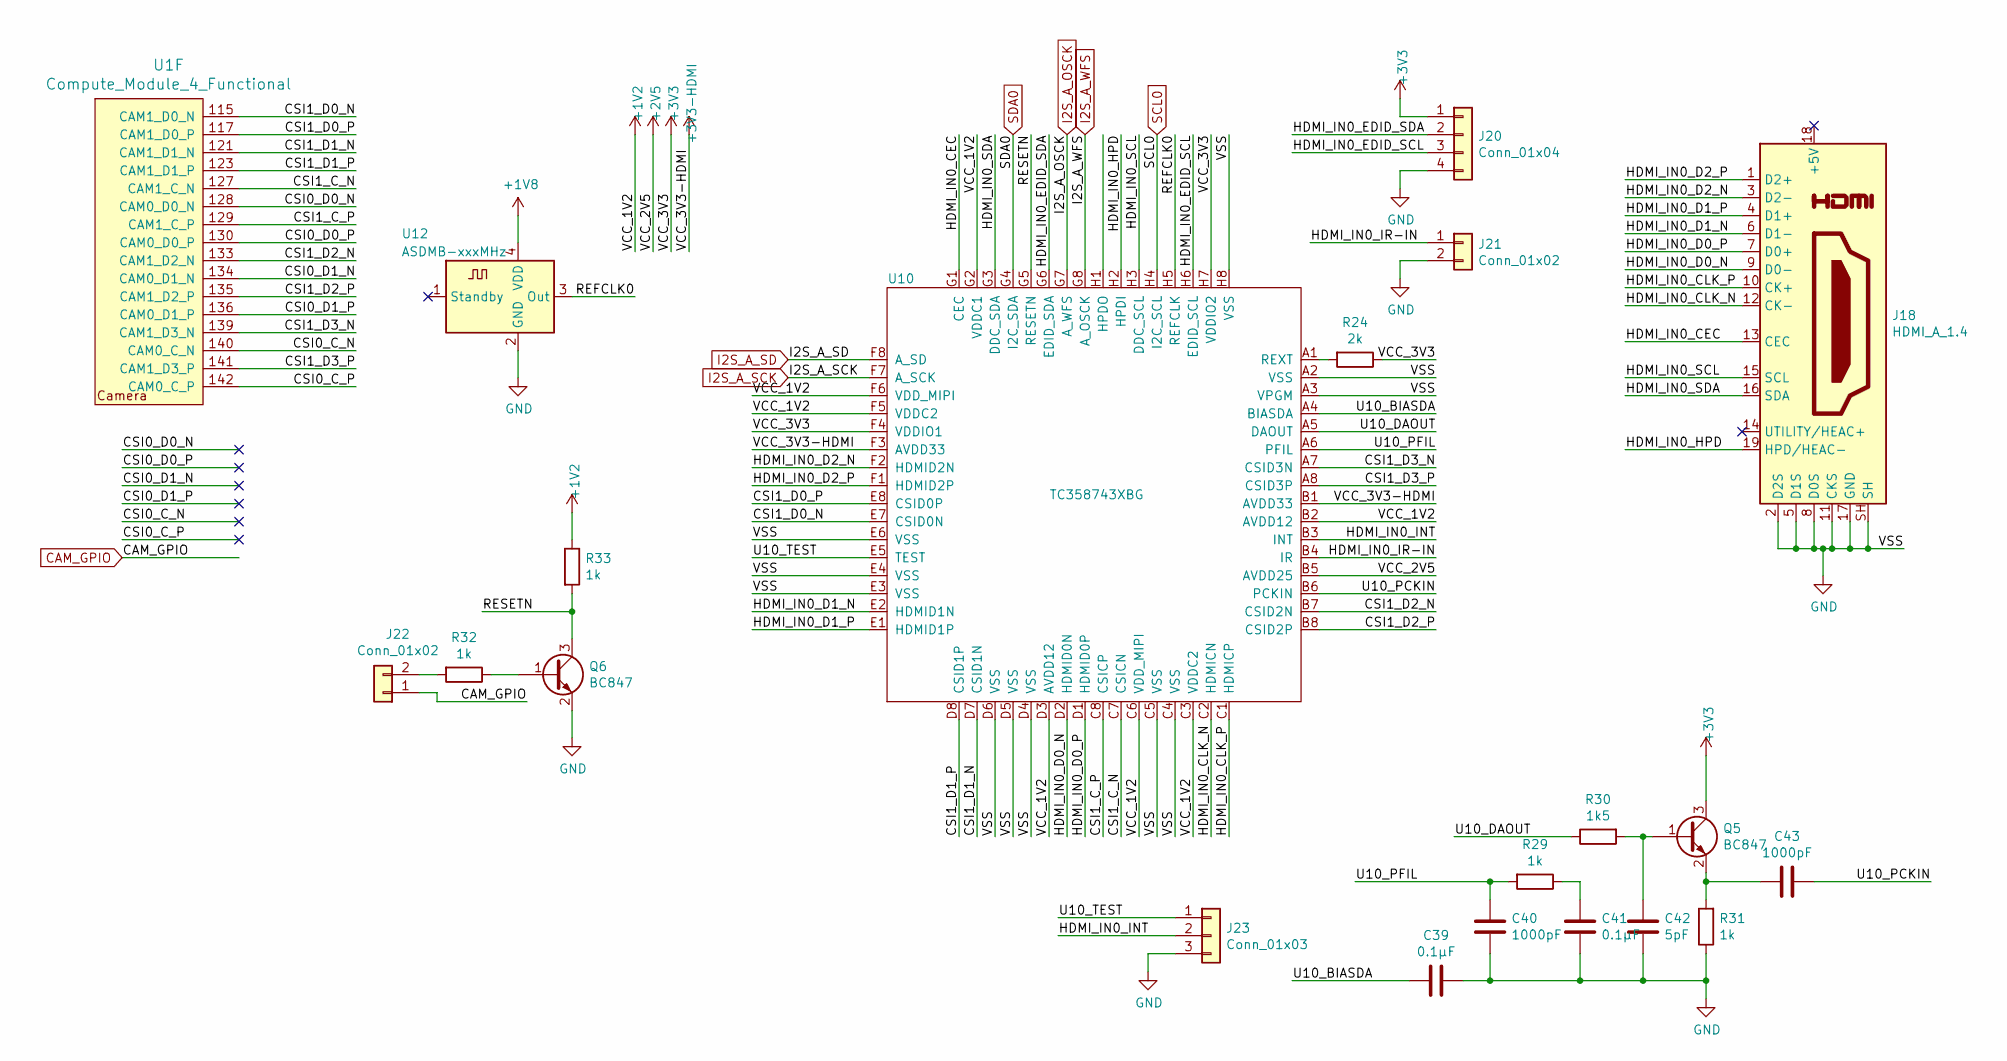
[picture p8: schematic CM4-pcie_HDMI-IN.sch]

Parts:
C39, C41: 0.1µF; C_0603_1608Metric_Pad1.08x0.95mm_HandSolder
C40, C43: 1000pF; C_0603_1608Metric_Pad1.08x0.95mm_HandSolder
C42: 5pF; C_0603_1608Metric_Pad1.08x0.95mm_HandSolder
J18: HDMI_A_1.4; HDMI_A_Kycon_KDMIX-SL1-NS-WS-B15_VerticalRightAngle
J20: Conn_01x04; PinHeader_1x04_P2.54mm_Vertical
J21, J22: Conn_01x02; PinHeader_1x02_P2.54mm_Vertical
J23: Conn_01x03; PinHeader_1x03_P2.54mm_Vertical
Q5, Q6: BC847; SOT-23
R24: 2k; R_0603_1608Metric_Pad0.98x0.95mm_HandSolder
R29, R31, R32, R33: 1k; R_0603_1608Metric_Pad0.98x0.95mm_HandSolder
R30: 1k5; R_0603_1608Metric_Pad0.98x0.95mm_HandSolder
U1: Compute_Module_4_Functional; Raspberry-Pi-4-Compute-Module
U10: TC358743XBG; TFBGA-64_5x5mm_Layout8x8_P0.5mm
U12: ASDMB-xxxMHz; Oscillator_SMD_Abracon_ASDMB-4Pin_2.5x2.0mm

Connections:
+1V2: R33.1, U10.B2 (AVDD12), U10.C3 (VDDC2), U10.C6 (VDD_MIPI), U10.D3 (AVDD12), U10.F5 (VDDC2), U10.F6 (VDD_MIPI), U10.G2 (VDDC1); also elsewhere on the board
+1V8: U12.4 (VDD); also elsewhere on the board
+2V5: U10.B5 (AVDD25); also elsewhere on the board
+3V3: J20.1, Q5.3 (C), R24.1, U10.F4 (VDDIO1), U10.H7 (VDDIO2); also elsewhere on the board
+3V3-HDMI: U10.B1 (AVDD33), U10.F3 (AVDD33); also elsewhere on the board
/Sheet611CBD44/CSI1_C_N: U1.127 (CAM1_C_N), U10.C7 (CSICN)
/Sheet611CBD44/CSI1_C_P: U1.129 (CAM1_C_P), U10.C8 (CSICP)
/Sheet611CBD44/CSI1_D0_N: U1.115 (CAM1_D0_N), U10.E7 (CSID0N)
/Sheet611CBD44/CSI1_D0_P: U1.117 (CAM1_D0_P), U10.E8 (CSID0P)
/Sheet611CBD44/CSI1_D1_N: U1.121 (CAM1_D1_N), U10.D7 (CSID1N)
/Sheet611CBD44/CSI1_D1_P: U1.123 (CAM1_D1_P), U10.D8 (CSID1P)
/Sheet611CBD44/CSI1_D2_N: U1.133 (CAM1_D2_N), U10.B7 (CSID2N)
/Sheet611CBD44/CSI1_D2_P: U1.135 (CAM1_D2_P), U10.B8 (CSID2P)
/Sheet611CBD44/CSI1_D3_N: U1.139 (CAM1_D3_N), U10.A7 (CSID3N)
/Sheet611CBD44/CSI1_D3_P: U1.141 (CAM1_D3_P), U10.A8 (CSID3P)
/Sheet611CBD44/HDMI_IN0_CEC: J18.13 (CEC), U10.G1 (CEC)
/Sheet611CBD44/HDMI_IN0_CLK_N: J18.12 (CK-), U10.C2 (HDMICN)
/Sheet611CBD44/HDMI_IN0_CLK_P: J18.10 (CK+), U10.C1 (HDMICP)
/Sheet611CBD44/HDMI_IN0_D0_N: J18.9 (D0-), U10.D2 (HDMID0N)
/Sheet611CBD44/HDMI_IN0_D0_P: J18.7 (D0+), U10.D1 (HDMID0P)
/Sheet611CBD44/HDMI_IN0_D1_N: J18.6 (D1-), U10.E2 (HDMID1N)
/Sheet611CBD44/HDMI_IN0_D1_P: J18.4 (D1+), U10.E1 (HDMID1P)
/Sheet611CBD44/HDMI_IN0_D2_N: J18.3 (D2-), U10.F2 (HDMID2N)
/Sheet611CBD44/HDMI_IN0_D2_P: J18.1 (D2+), U10.F1 (HDMID2P)
/Sheet611CBD44/HDMI_IN0_EDID_SCL: J20.3, U10.H6 (EDID_SCL)
/Sheet611CBD44/HDMI_IN0_EDID_SDA: J20.2, U10.G6 (EDID_SDA)
/Sheet611CBD44/HDMI_IN0_HPD: J18.19 (HPD/HEAC-), U10.H2 (HPDI)
/Sheet611CBD44/HDMI_IN0_INT: J23.2, U10.B3 (INT)
/Sheet611CBD44/HDMI_IN0_IR-IN: J21.1, U10.B4 (IR)
/Sheet611CBD44/HDMI_IN0_SCL: J18.15 (SCL), U10.H3 (DDC_SCL)
/Sheet611CBD44/HDMI_IN0_SDA: J18.16 (SDA), U10.G3 (DDC_SDA)
/Sheet611CBD44/REFCLK0: U10.H5 (REFCLK), U12.3 (Out)
/Sheet611CBD44/RESETN: Q6.3 (C), R33.2, U10.G5 (RESETN)
/Sheet611CBD44/U10_BIASDA: C39.2, U10.A4 (BIASDA)
/Sheet611CBD44/U10_DAOUT: R30.1, U10.A5 (DAOUT)
/Sheet611CBD44/U10_PCKIN: C43.1, U10.B6 (PCKIN)
/Sheet611CBD44/U10_PFIL: C40.1, R29.2, U10.A6 (PFIL)
/Sheet611CBD44/U10_TEST: J23.1, U10.E5 (TEST)
CAM_GPIO: J22.1; also elsewhere on the board
GND: C39.1, C40.2, C41.2, C42.2, J18.2 (D2S), J18.5 (D1S), J18.8 (D0S), J18.11 (CKS), J18.17 (GND), J18.SH, J20.4, J21.2, J23.3, Q6.2 (E), R31.1, U10.A2 (VSS), U10.A3 (VPGM), U10.C4 (VSS), U10.C5 (VSS), U10.D4 (VSS), U10.D5 (VSS), U10.D6 (VSS), U10.E3 (VSS), U10.E4 (VSS), U10.E6 (VSS), U10.H8 (VSS), U12.2 (GND); also elsewhere on the board
I2S_A_OSCK: U10.G7 (A_WFS); also elsewhere on the board
I2S_A_SCK: U10.F7 (A_SCK); also elsewhere on the board
I2S_A_SD: U10.F8 (A_SD); also elsewhere on the board
I2S_A_WFS: U10.G8 (A_OSCK); also elsewhere on the board
unnamed: C41.1, R29.1
unnamed: C42.1, Q5.1 (B), R30.2
unnamed: C43.2, Q5.2 (E), R31.2
unnamed: J22.2, R32.2
unnamed: Q6.1 (B), R32.1
unnamed: R24.2, U10.A1 (REXT)
SCL0: U10.H4 (I2C_SCL); also elsewhere on the board
SDA0: U10.G4 (I2C_SDA); also elsewhere on the board

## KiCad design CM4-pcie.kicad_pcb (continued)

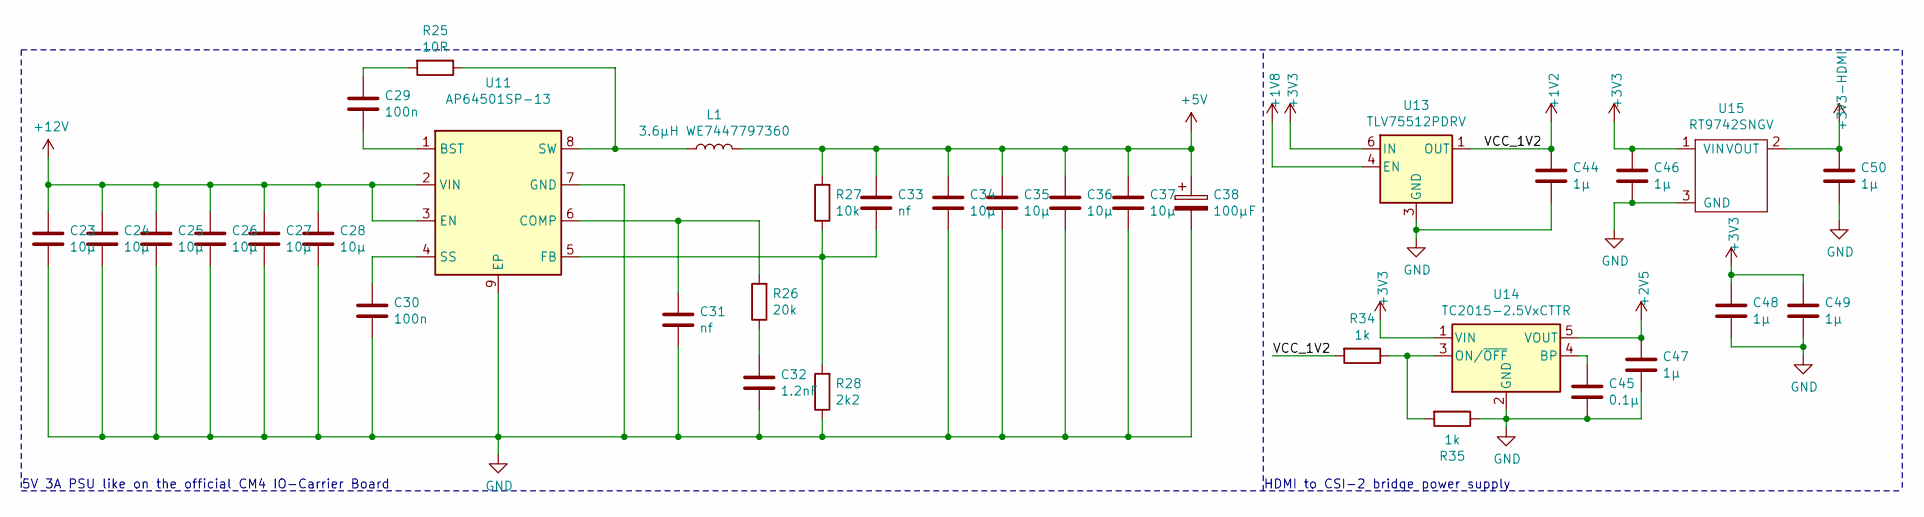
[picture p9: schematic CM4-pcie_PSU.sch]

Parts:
C23, C24, C25, C26, C27, C28, C34, C35, C36, C37: 10µ; C_0603_1608Metric_Pad1.08x0.95mm_HandSolder
C29, C30: 100n; C_0603_1608Metric_Pad1.08x0.95mm_HandSolder
C31, C33: nf; C_0603_1608Metric_Pad1.08x0.95mm_HandSolder
C32: 1.2nF; C_0603_1608Metric_Pad1.08x0.95mm_HandSolder
C38: 100µF; CP_Elec_6.3x5.4_Nichicon
C44, C46, C47, C48, C49, C50: 1µ; C_0603_1608Metric_Pad1.08x0.95mm_HandSolder
C45: 0.1µ; C_0603_1608Metric_Pad1.08x0.95mm_HandSolder
L1: 3.6µH WE7447797360; L_Wuerth_WE-PDF_Handsoldering
R25: 10R; R_0603_1608Metric_Pad0.98x0.95mm_HandSolder
R26: 20k; R_0603_1608Metric_Pad0.98x0.95mm_HandSolder
R27: 10k; R_0603_1608Metric_Pad0.98x0.95mm_HandSolder
R28: 2k2; R_0603_1608Metric_Pad0.98x0.95mm_HandSolder
R34, R35: 1k; R_0603_1608Metric_Pad0.98x0.95mm_HandSolder
U11: AP64501SP-13; Diodes_SO-8EP
U13: TLV75512PDRV; WSON-6-1EP_2x2mm_P0.65mm_EP1x1.6mm
U14: TC2015-2.5VxCTTR; SOT-23-5
U15: RT9742SNGV; SOT-23

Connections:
+1V2: C44.1, R34.2, U13.1 (OUT); also elsewhere on the board
+1V8: U13.4 (EN); also elsewhere on the board
+2V5: C47.1, U14.5 (VOUT); also elsewhere on the board
+3V3: C46.1, C48.1, C49.1, U13.6 (IN), U14.1 (VIN), U15.1 (VIN); also elsewhere on the board
+3V3-HDMI: C50.1, U15.2 (VOUT); also elsewhere on the board
+5V: C33.1, C34.1, C35.1, C36.1, C37.1, C38.1, L1.2, R27.2; also elsewhere on the board
+12V: C23.1, C24.1, C25.1, C26.1, C27.1, C28.1, U11.2 (VIN), U11.3 (EN); also elsewhere on the board
GND: C23.2, C24.2, C25.2, C26.2, C27.2, C28.2, C30.2, C31.2, C32.2, C34.2, C35.2, C36.2, C37.2, C38.2, C44.2, C45.2, C46.2, C47.2, C48.2, C49.2, C50.2, R28.1, R35.1, U11.7 (GND), U11.9 (EP), U13.3 (GND), U13.7 (GND), U14.2 (GND), U15.3 (GND); also elsewhere on the board
unnamed: C29.1, R25.2
unnamed: C29.2, U11.1 (BST)
unnamed: C30.1, U11.4 (SS)
unnamed: C31.1, R26.2, U11.6 (COMP)
unnamed: C32.1, R26.1
unnamed: C33.2, R27.1, R28.2, U11.5 (FB)
unnamed: C45.1, U14.4 (BP)
unnamed: L1.1, R25.1, U11.8 (SW)
unnamed: R34.1, R35.2, U14.3 (ON/~OFF~)

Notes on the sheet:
5V 3A PSU like on the official CM4 IO-Carrier Board
HDMI to CSI-2 bridge power supply

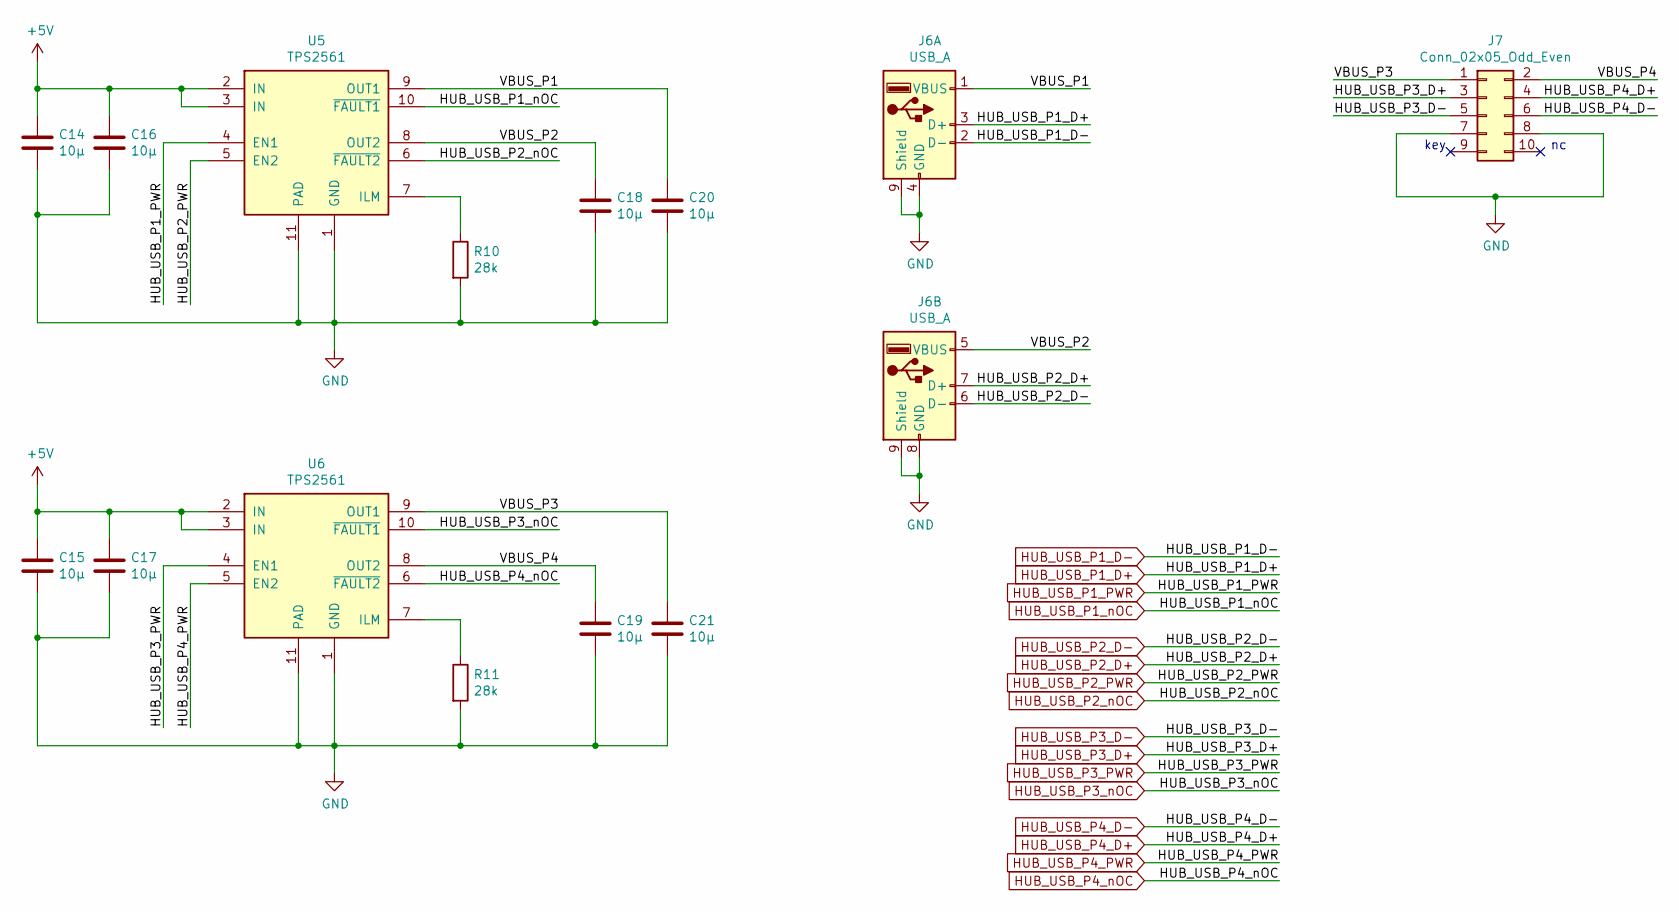
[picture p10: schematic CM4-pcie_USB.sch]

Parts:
C14, C15, C16, C17, C18, C19, C20, C21: 10µ; C_0603_1608Metric_Pad1.08x0.95mm_HandSolder
J6: USB_A; USB_A_Wuerth_61400826021_Horizontal_Stacked
J7: Conn_02x05_Odd_Even; PinHeader_2x05_P2.54mm_Vertical
R10, R11: 28k; R_0603_1608Metric_Pad0.98x0.95mm_HandSolder
U5, U6: TPS2561; VSON-10-1EP_3x3mm_P0.5mm_EP1.65x2.4mm_ThermalVias

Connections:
+5V: C14.1, C15.1, C16.1, C17.1, U5.2 (IN), U5.3 (IN), U6.2 (IN), U6.3 (IN); also elsewhere on the board
/Sheet606D5A30/Sheet60CE0192/VBUS_P1: C20.1, J6.1 (VBUS), U5.9 (OUT1)
/Sheet606D5A30/Sheet60CE0192/VBUS_P2: C18.1, J6.5 (VBUS), U5.8 (OUT2)
/Sheet606D5A30/Sheet60CE0192/VBUS_P3: C21.1, J7.1, U6.9 (OUT1)
/Sheet606D5A30/Sheet60CE0192/VBUS_P4: C19.1, J7.2, U6.8 (OUT2)
GND: C14.2, C15.2, C16.2, C17.2, C18.2, C19.2, C20.2, C21.2, J6.4 (GND), J6.8 (GND), J6.9 (Shield), J7.7, J7.8, R10.2, R11.2, U5.1 (GND), U5.11 (PAD), U6.1 (GND), U6.11 (PAD); also elsewhere on the board
HUB_USB_P1_D+: J6.3 (D+); also elsewhere on the board
HUB_USB_P1_D-: J6.2 (D-); also elsewhere on the board
HUB_USB_P1_PWR: U5.4 (EN1); also elsewhere on the board
HUB_USB_P1_nOC: U5.10 (~FAULT1); also elsewhere on the board
HUB_USB_P2_D+: J6.7 (D+); also elsewhere on the board
HUB_USB_P2_D-: J6.6 (D-); also elsewhere on the board
HUB_USB_P2_PWR: U5.5 (EN2); also elsewhere on the board
HUB_USB_P2_nOC: U5.6 (~FAULT2); also elsewhere on the board
HUB_USB_P3_D+: J7.3; also elsewhere on the board
HUB_USB_P3_D-: J7.5; also elsewhere on the board
HUB_USB_P3_PWR: U6.4 (EN1); also elsewhere on the board
HUB_USB_P3_nOC: U6.10 (~FAULT1); also elsewhere on the board
HUB_USB_P4_D+: J7.4; also elsewhere on the board
HUB_USB_P4_D-: J7.6; also elsewhere on the board
HUB_USB_P4_PWR: U6.5 (EN2); also elsewhere on the board
HUB_USB_P4_nOC: U6.6 (~FAULT2); also elsewhere on the board
unnamed: R10.1, U5.7 (ILM)
unnamed: R11.1, U6.7 (ILM)

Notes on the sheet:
key

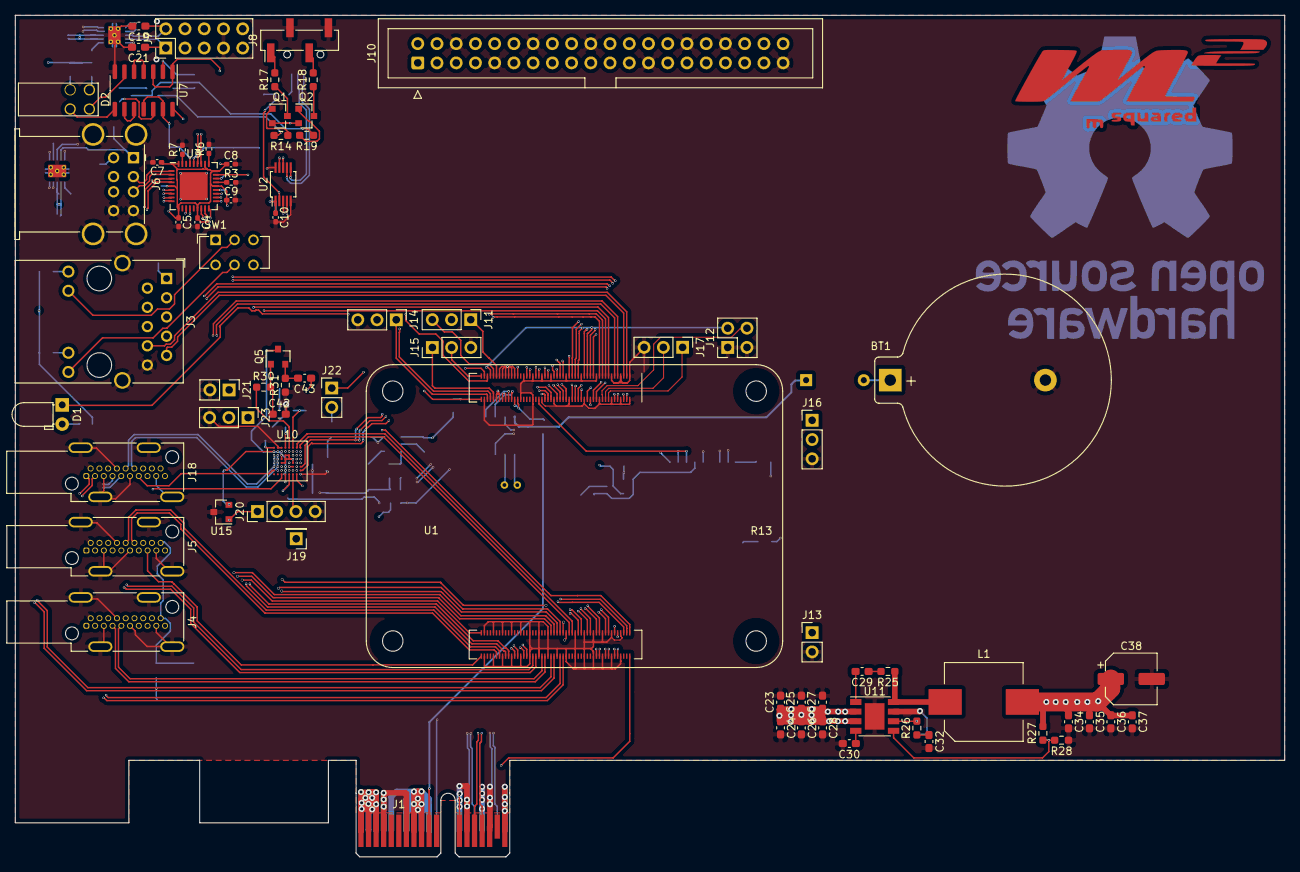
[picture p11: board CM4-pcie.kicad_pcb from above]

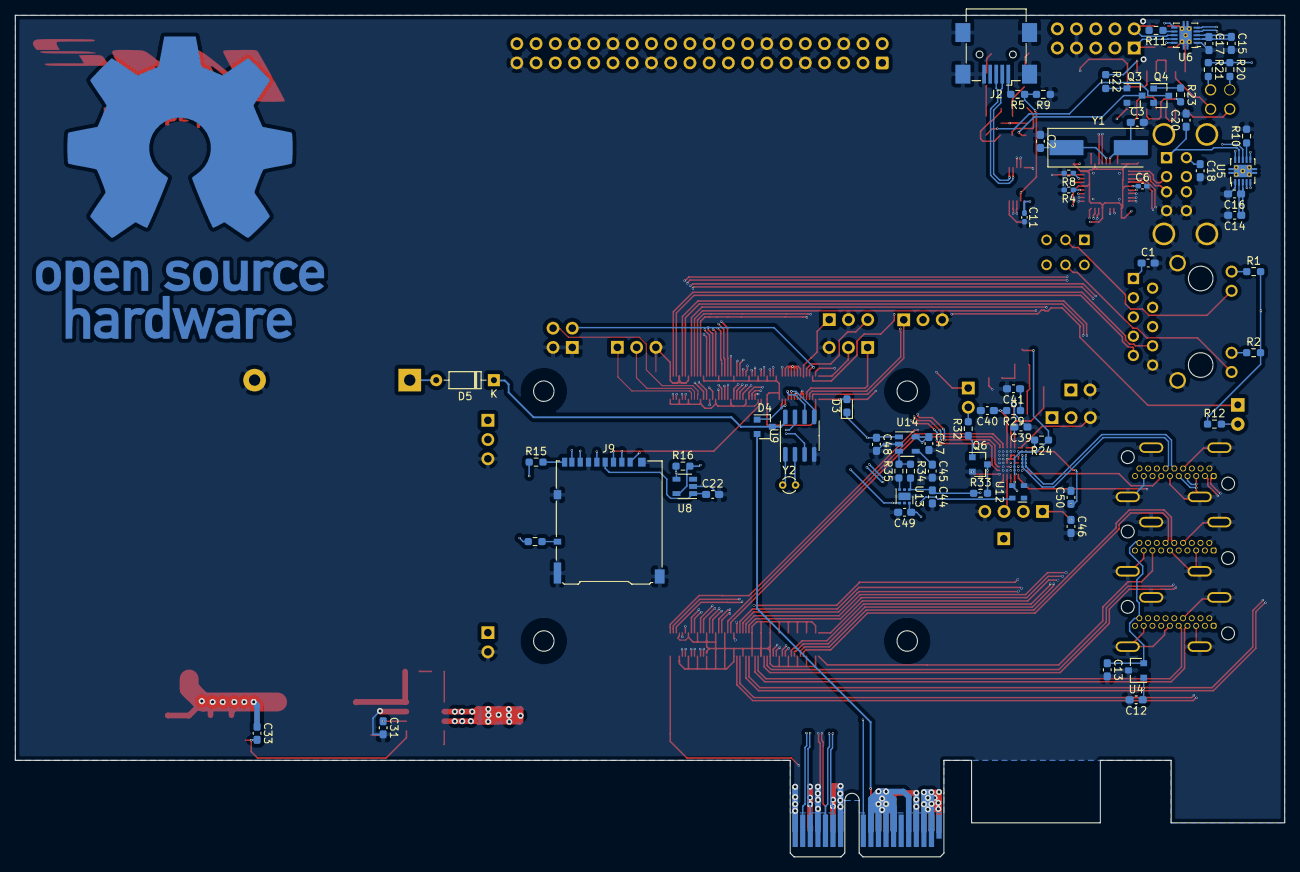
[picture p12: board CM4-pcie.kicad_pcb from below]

Board: 6 copper layers, 167.7 x 111.2 mm, 139 parts (66 on the bottom side), 226 nets.
